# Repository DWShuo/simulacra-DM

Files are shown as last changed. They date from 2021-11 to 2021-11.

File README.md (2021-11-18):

# simulacra-DM
Dactyl Manuform - Simulacra edition
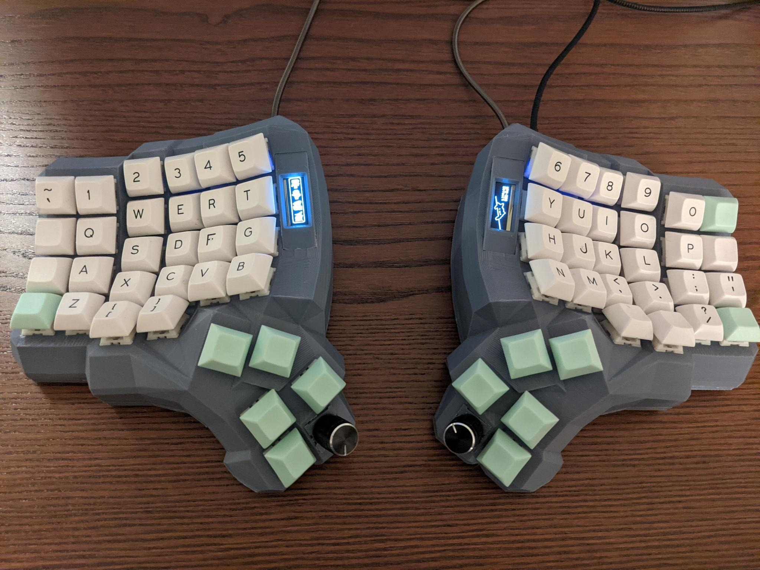
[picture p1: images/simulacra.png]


## Bill of materials

* 3D printed matrials
  * Case: Both sides top and bottom    - (x2)
  * External tray                      - (x2)
  * EC11 adapters for rotatry encoders - (x2)
  * OLED cover                         - (x2)
* 1N4148 diodes                        - (x64)
* Elite C or Pro Micro controllers     - (x2)
* SSD1306 128x32 OLED Display          - (x2)
* EC11 rotary encoders                 - (x2)
* Kailh hot swap sockets               - (x62)
* Switches                             - (x62)
* Keycaps                              - (x62)
* M4xD6.0xL5.5 brass screw insert      - (x10)
* M4 screw / #6-32 x 1/2 IN            - (x10)
* TRRS cable
* Single core wire

## Setup

### Setup QMK build enviroment
1. Setup QMK build environment https://beta.docs.qmk.fm/tutorial/newbs_getting_started#linux-wsl
2. Move simulacra folder into `qmk_firmware/keyboards/handwired/`

### Firmware
Compile and flash the firmware to each side of the keyboard.

After flashing for the first time the Func layer contains a RESET key for each side of the keyboard.
#### Compile firmware
`qmk compile -kb handwired/simulacra -km default -e PREPROCESSOR=RIGHT`

`qmk compile -kb handwired/simulacra -km default -e PREPROCESSOR=LEFT`

#### Flashing firmware
`qmk flash -kb handwired/simulacra -km default -bl dfu-split-right -e PREPROCESSOR=RIGHT`

`qmk flash -kb handwired/simulacra -km default -bl dfu-split-left -e PREPROCESSOR=LEFT`

## Keyboard Layout
#### [_QWERTY] = LAYOUT
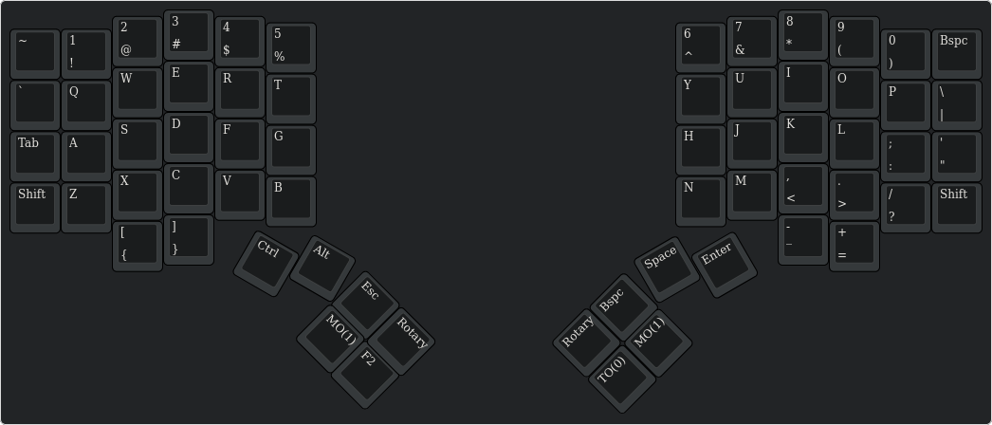
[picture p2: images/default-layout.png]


#### [_FUNC] = LAYOUT
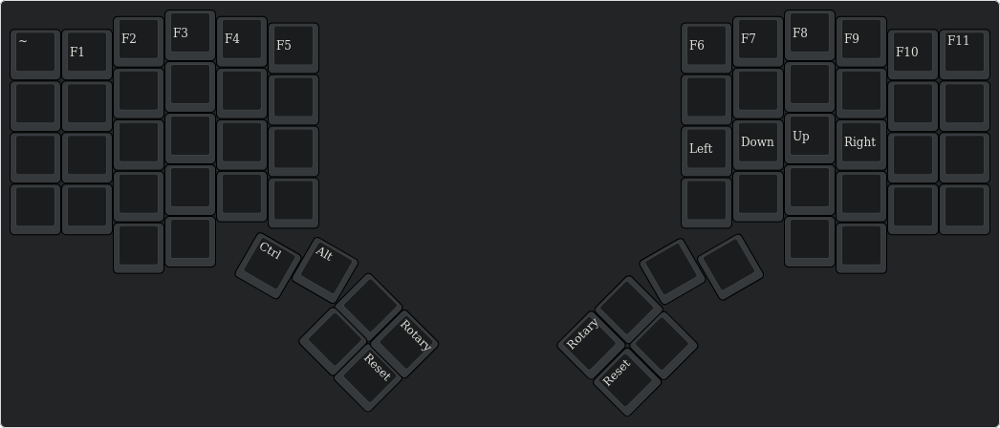
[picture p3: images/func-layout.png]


#### [_GAMING] = LAYOUT
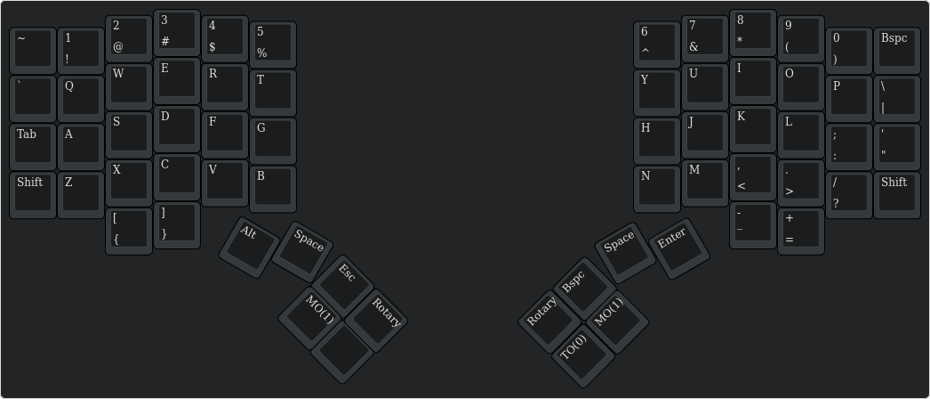
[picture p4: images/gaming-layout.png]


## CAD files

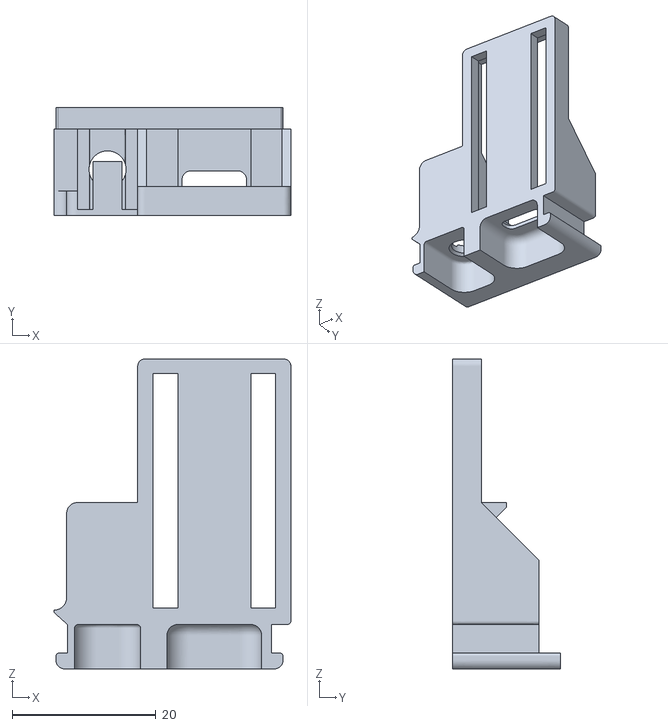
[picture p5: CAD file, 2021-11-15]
stl/External-Tray-Elite-C.stl
33.0 x 15.0 x 43.2

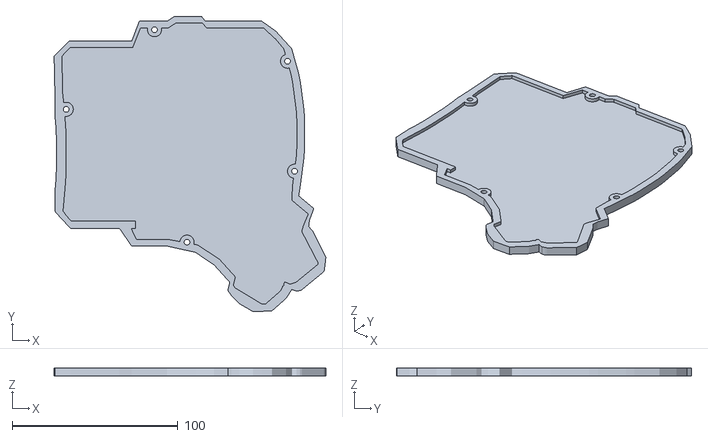
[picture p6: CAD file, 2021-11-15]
stl/left-bottom-plate.stl
164.2 x 178.1 x 5.00

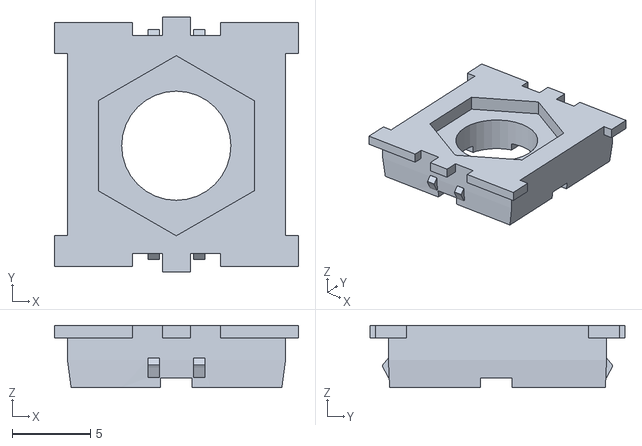
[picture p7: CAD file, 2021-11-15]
stl/EC11_to_MX_Adapter.stl
15.6 x 16.3 x 4.00

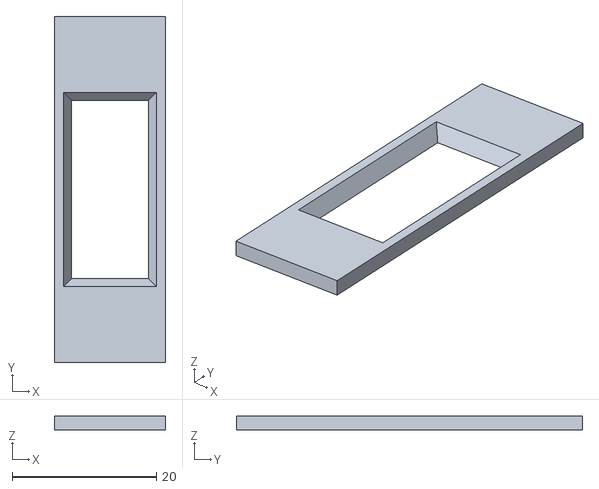
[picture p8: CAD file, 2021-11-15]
stl/oled-cover-snapfit.stl
15.4 x 47.9 x 2.00

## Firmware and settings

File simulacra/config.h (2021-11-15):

#pragma once

#include "config_common.h"

/* USB Device descriptor parameter */
#define VENDOR_ID       0xe70c
#define PRODUCT_ID      0x9ed8
#define DEVICE_VER      0x0001
#define MANUFACTURER    DWShuo 

// defined in subfolder
#define DESCRIPTION     Dactyl Manuform - Simulacra edition
#define PRODUCT         Simulacra 5x6

/* mouse config */
#define MOUSEKEY_INTERVAL       20
#define MOUSEKEY_DELAY          0
#define MOUSEKEY_TIME_TO_MAX    60
#define MOUSEKEY_MAX_SPEED      7
#define MOUSEKEY_WHEEL_DELAY    0

/* Set 0 if debouncing isn't needed */
#define DEBOUNCE 5

/* serial.c configuration for split keyboard */
#define SOFT_SERIAL_PIN D2

/* Mechanical locking support. Use KC_LCAP, KC_LNUM or KC_LSCR instead in keymap */
#define LOCKING_SUPPORT_ENABLE
/* Locking resynchronize hack */
#define LOCKING_RESYNC_ENABLE

/* Enables This makes it easier for fast typists to use dual-function keys */
//#define PERMISSIVE_HOLD

/* key matrix size */
// Rows are doubled-up
#define MATRIX_ROWS 12
#define MATRIX_COLS 6

// wiring of each half
#define MATRIX_COL_PINS { D4, C6, D7, E6, B4, B5 }
#define MATRIX_ROW_PINS { F6, F7, B1, B3, B2, B6 }

#define DIODE_DIRECTION COL2ROW

/* define if matrix has ghost */
// #define MATRIX_HAS_GHOST

// wiring of the encoder (right side)
#define ENCODERS_PAD_A { F4 }
#define ENCODERS_PAD_B { F5 }

// define de timing for the tap dance time out
 //#define TAPPING_TERM 200

/*
 * Feature disable options
 *  These options are also useful to firmware size reduction.
*/

/* disable debug print */
// #define NO_DEBUG

/* disable print */
// #define NO_PRINT

/* disable action features */
//#define NO_ACTION_LAYER
//#define NO_ACTION_TAPPING
#define LAYER_STATE_8BIT // If using low layer count, use to reduce firmware size
#define NO_ACTION_ONESHOT
#define NO_ACTION_MACRO
#define NO_ACTION_FUNCTION

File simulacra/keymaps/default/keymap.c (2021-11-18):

#include QMK_KEYBOARD_H
#include <stdio.h>
char wpm_str[10];

extern keymap_config_t keymap_config;
#define _QWERTY   0
#define _FUNC     1
#define _GAMING   2  

//==========================================
// CUSTOM KEYCODES DEFINITION
//==========================================

const uint16_t PROGMEM keymaps[][MATRIX_ROWS][MATRIX_COLS] = {

  [_QWERTY] = LAYOUT(
     KC_TILD  , KC_1  , KC_2    ,   KC_3  , KC_4  ,   KC_5  ,        KC_6   ,   KC_7  ,   KC_8  ,   KC_9    , KC_0    , KC_BSPC ,
     KC_GRAVE , KC_Q  , KC_W    ,   KC_E  , KC_R  ,   KC_T  ,        KC_Y   ,   KC_U  ,   KC_I  ,   KC_O    , KC_P    , KC_BSLS ,
     KC_TAB   , KC_A  , KC_S    ,   KC_D  , KC_F  ,   KC_G  ,        KC_H   ,   KC_J  ,   KC_K  ,   KC_L    , KC_SCLN , KC_QUOT ,
     KC_LSFT  , KC_Z  , KC_X    ,   KC_C  , KC_V  ,   KC_B  ,        KC_N   ,   KC_M  ,   KC_COMM,  KC_DOT  , KC_SLSH , KC_RSFT ,
                        KC_LBRC ,   KC_RBRC,                                              KC_MINS,  KC_EQL,
                                   KC_LCTL, KC_LALT,                           KC_SPC, KC_ENT,
                                         MO(_FUNC) , KC_ESC,         KC_BSPC , MO(_FUNC),
                                         KC_F2 , KC_MPLY,            KC_HOME , TO(_GAMING)
  ),

  [_FUNC] = LAYOUT(
     KC_TILD , KC_F1   , KC_F2   , KC_F3   , KC_F4   , KC_F5  ,      KC_F6   , KC_F7   , KC_F8   , KC_F9   , KC_F10  , KC_F11 ,
     _______ , _______ , _______ , _______ , _______ , _______,      _______ , _______ , _______ , _______ , _______ , _______,
     _______ , _______ , _______ , _______ , _______ , _______,      KC_LEFT , KC_DOWN , KC_UP   , KC_RIGHT , _______ , _______,
     _______ , _______ , _______ , _______ , _______ , _______,      _______ , _______ , _______ , _______ , _______ , _______,
                         _______ , _______ ,                                             _______ , _______ ,
                                    KC_LCTL,  KC_LALT,                         _______, _______ ,
                                             _______ , _______  ,    _______  , _______,
                                             _______ , RESET    ,    RESET    , _______

  ),

  [_GAMING] = LAYOUT(
     KC_TILD  , KC_1  , KC_2    ,   KC_3  , KC_4  ,   KC_5  ,        KC_6   ,   KC_7  ,   KC_8  ,   KC_9    , KC_0    , KC_BSPC,
     KC_ESC   , KC_Q  , KC_W    ,   KC_E  , KC_R  ,   KC_T  ,        KC_Y   ,   KC_U  ,   KC_I  ,   KC_O    , KC_P    , KC_BSLS ,
     KC_TAB   , KC_A  , KC_S    ,   KC_D  , KC_F  ,   KC_G  ,        KC_H   ,   KC_J  ,   KC_K  ,   KC_L    , KC_SCLN , KC_QUOT ,
     KC_GRAVE , KC_Z  , KC_X    ,   KC_C  , KC_V  ,   KC_B  ,        KC_N   ,   KC_M  ,   KC_COMM,  KC_DOT  , KC_SLSH , KC_RSFT ,
                        KC_LBRC ,   KC_RBRC,                                              KC_MINS,  KC_EQL,
                                   KC_LCTL, KC_SPC,                           KC_SPC, KC_ENT,
                                         KC_LALT , KC_LSFT,          KC_BSPC , MO(_FUNC),
                                         MO(_FUNC) , KC_MPLY,        KC_HOME , TO(_QWERTY)
  ), 
};

//==========================================

//==========================================
// ENCODERS DEFINITIOM
//==========================================

bool encoder_update_user(uint8_t index, bool clockwise) {
    if (index == 0) { /* First encoder */
        if(IS_LAYER_ON(_FUNC)) {
            if (clockwise) {
                tap_code(KC_MPRV);
            } else {
                tap_code(KC_MNXT);
            }
        } else { 
            if (clockwise) {
                tap_code(KC_VOLD);
            } else {
                tap_code(KC_VOLU);
            }
        }
    } else if (index == 1) { /* Second encoder */
        if(IS_LAYER_ON(_FUNC)) {
            if (clockwise) {
                tap_code(KC_BRID);
            } else {
                tap_code(KC_BRIU);
            }
        } else { 
            if (clockwise) {
                tap_code(KC_DOWN);
            } else {
                tap_code(KC_UP);
            }
        }
    }
    return true;
}

//==========================================
// OLED DEFINITIOM
//==========================================
// OLED STUFF STARTS HERE

// In your rules.mk make sure you have:
// OLED_DRIVER_ENABLE = yes
// WPM_ENABLE = yes

#ifdef OLED_ENABLE

#ifdef RIGHT
// WPM-responsive animation stuff here
#    define IDLE_FRAMES 5
#    define IDLE_SPEED 20  // below this wpm value your animation will idle
#    define TAP_FRAMES 2
#    define TAP_SPEED 40  // above this wpm value typing animation to trigger
#    define ANIM_FRAME_DURATION 200  // how long each frame lasts in ms
//   #define SLEEP_TIMER 60000 // should sleep after this period of 0 wpm, needs fixing
#    define ANIM_SIZE 636  // number of bytes in array, minimize for adequate firmware size, max is 1024

uint32_t anim_timer         = 0;
uint32_t anim_sleep         = 0;
uint8_t  current_idle_frame = 0;
// uint8_t current_prep_frame = 0; // uncomment if PREP_FRAMES >1
uint8_t current_tap_frame = 0;

// Code containing pixel art, contains:
// 5 idle frames, 1 prep frame, and 2 tap frames
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

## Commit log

2021-11-15 Inital firmware and STL files
    [EC11_to_MX_Adapter.stl, External-Tray-Elite-C.stl, left-bottom-plate.stl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]
2021-11-15 added bill of materials
